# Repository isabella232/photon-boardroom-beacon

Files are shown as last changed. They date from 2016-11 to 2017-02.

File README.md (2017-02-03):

# photon-boardroom-beacon
The boardroom beacon is a physical device mounted to the exterior wall of a boardroom. It has 3 lights indicating meeting room availability in half hour allotments. The first light indicates the boardroom status for the current half hour, the second indicates the next half hour and the third, the half hour after that. So any casual observer can see what the boardroom’s status is, for the next hour and a half. Statuses include “available” (green), “booked” (red) and “illegal” (yellow). An illegal status indicates that a person is in the room but it is not booked. Malfunction will be indicated by all three lights flashing yellow.
##Run
You will need to flash this code to your photon and use the component configurations in the diagram below. When the Photon first plugged in, all the LEDs should blink blue which means it is connected to wifi and waiting for a status message from Mosquitto. Beneath the schematic are instructions on how to send updates to the Photon. The 3D model for the enclosure is also included in this repo as a Sketchup file.
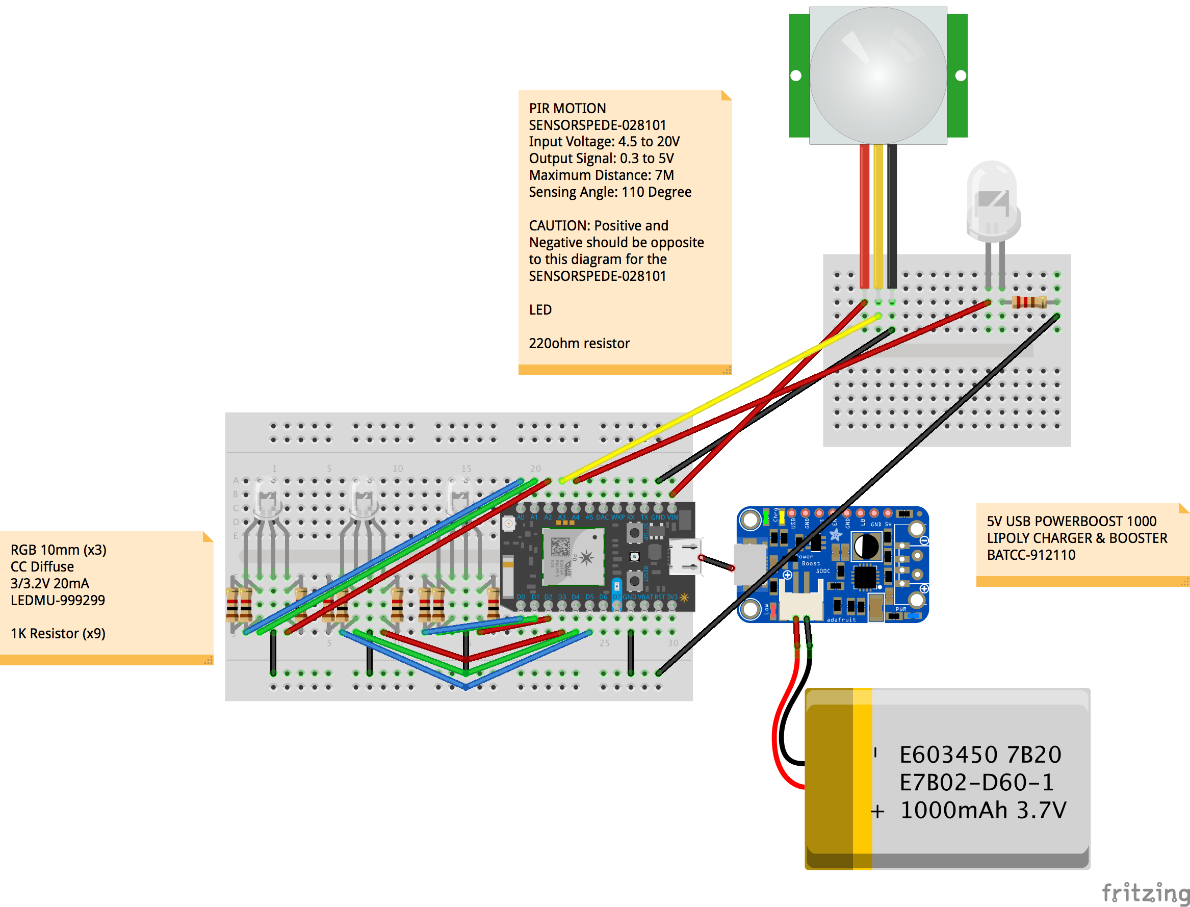
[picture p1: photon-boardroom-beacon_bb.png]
Fritzing

<table>
  <thead>
	<tr>
    <th>Amount</th>
    <th>Part Type</th>
    <th>Properties</th>
    </tr>
  </thead>
  <tbody>
<tr>
    <td>3</td>
    <td>RGB LED (com. cathode, rgb)</td>
    <td class="props">polarity common cathode; pin order rgb; package 5 mm [THT]; rgb RGB; part # LEDMU-999299</td>
</tr><tr>
    <td>1</td>
    <td>LEDs</td>
    <td class="props">variant 10mm; package led10mm</td>
</tr><tr>
    <td>1</td>
    <td>Photon</td>
    <td class="props">pins 24; variant variant 1; name Photon; version 1.0.0; manufacturer Particle</td>
</tr><tr>
    <td>1</td>
    <td>PowerBoost 500 Charger</td>
    <td class="props">variant variant 1; input connector JST; output connector USB</td>
</tr><tr>
    <td>1</td>
    <td>PIR sensor</td>
    <td class="props"></td>
</tr><tr>
    <td>9</td>
    <td>1kΩ Resistor</td>
    <td class="props">resistance 1kΩ; package 2010 [SMD]; tolerance ±5%</td>
</tr><tr>
    <td>1</td>
    <td>220Ω Resistor</td>
    <td class="props">resistance 220Ω; package 1206 [SMD]; tolerance ±5%</td>
</tr><tr>
    <td>1</td>
    <td>LIPO-1000mAh</td>
    <td class="props">variant 1000mAh; package lipo-1000</td>
</tr>
  </tbody>
</table>

##Communicate with the Boardroom-Beacon
This code is meant to work with [Mosquitto MQTT](https://mosquitto.org/) server and [Home Assistant](https://home-assistant.io/). For the photon to get the right calendar data, HASS uses a custom component and configuration [found here](https://github.com/Jam3/.homeassistant). If you don't want to install HASS you can use the Boardroom-Beacon without it by sending messages to Mosquitto through the command line.

###Install Mosquitto
[Download](https://mosquitto.org/download/)
Brew: `brew install mosquitto`

###Update the Mosquitto Configuration File
OSX: `/usr/local/sbin/mosquitto/mosquitto.conf`
Linux: `/etc/mosquitto/mosquitto.conf`

Add the following lines to the very end with your ip & port:
```
# Mosquittoo server IP & port
listener 8883 192.168.2.115
persistence true
persistence_location /var/lib/mosquitto/
persistence_file mosquitto.db
log_dest syslog
log_dest stdout
log_dest topic
log_type error
log_type warning
log_type notice
log_type information
connection_messages true
log_timestamp true
allow_anonymous true
# Add a password https://mosquitto.org/man/mosquitto_passwd-1.html
#password_file /usr/local/etc/mosquitto/pwfile
```
###Run Mosquitto
OSX:
`/usr/local/sbin/mosquitto -c /usr/local/etc/mosquitto/mosquitto.conf`

Brew Background Service(OSX):
`brew services start mosquitto`

Linux:
`sudo mosquitto -v -c /etc/mosquitto/mosquitto.conf`

Background Service (Linux):
`sudo service mosquitto start`

###Publish and Subscribe
You may need to install `mosquitto_sub` & `mosquitto_pub` with Pip3
If you want to verify that Mosquitto is running properly and messages are being sent, you can use `mosquitto_sub`.

`mosquitto_sub -h <your-ip> -p 8883 -v -t 'homeassistant/boardroomBeacon/biggie/slot/0' -u <user> -P <password>`

Omit the user and password if you are not using a `pwfile` file.

Each LED subscribes to its own `slot` topic, `/slot/0`, `/slot/1` or `/slot/2`.
Publish to the status (booked, free, illegal) to the "biggie" boardroom:

`mosquitto_pub -h <your-ip> -p 8883 -t 'homeassistant/boardroomBeacon/biggie/slot/0' -m 'booked'`

The first LED should turn red.

`mosquitto_pub -h <your-ip> -p 8883 -t 'homeassistant/boardroomBeacon/biggie/slot/1' -m 'free'`
The second LED should turn green.

If you move around infront of the motion sensor the first LED should turn yellow.

####Subscribe
`mosquitto_sub -h 192.168.2.115 -p 8883 -v -t 'homeassistant/boardroomBeacon/biggie/slot/0'`
####Publish
`mosquitto_pub -h 192.168.2.115 -p 8883 -t 'homeassistant/boardroomBeacon/biggie/slot/0' -m 'free'`
####Publish wt Credentials
`mosquitto_pub -h 192.168.2.115 -p 8883 -t 'homeassistant/boardroomBeacon/biggie/slot/0' -u "<user>" -P "<password>" -m 'booked'`

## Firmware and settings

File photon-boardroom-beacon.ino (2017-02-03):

#include "SparkJson.h"
#include "MQTT.h"

boolean test = true;
int testLed = D7;
int led1[] = {D0, D1, D2}; //rgb
int led2[] = {D3, D4, D5};
int led3[] = {A0, A1, A2};
// int led3[] = {A2, A1, A0};
String slot1Satus = "";
String slot2Satus = "";
String slot3Satus = "";
boolean slot1HasRecievedMessage = false;
boolean slot2HasRecievedMessage = false;
boolean slot3HasRecievedMessage = false;
boolean isConnected = false;

int pirStatusLed = D7;
int pirInputPin = D6;
int prevPirState = LOW;             // we start, assuming no motion detected
int currentPirState = 0;            // variable for reading the pin status
int calibrateTime = 10000;      // wait for the pir sensor to calibrate

// Generally, you should use "unsigned long" for variables that hold time
// The value will quickly become too large for an int to store
unsigned long previousMillis = 0;        // will store last time LED was updated
unsigned long lastMotionMillis = 0;        // will store last time LED was updated
const long interval = 5000;           // interval at which to blink (milliseconds)

// Log message to cloud, message is a printf-formatted string
void debug(String message, int value) {
    char msg [50];
    sprintf(msg, message.c_str(), value);
    Spark.publish("DEBUG", msg);
    Serial.println(msg);
}

// MQTT
// url structure: /homeassistant/boardroomBeacon/<roomID>/slot/<slotID>/status/<[booked, free, illegal]>
// mosquitto_pub -h 192.168.2.115 -p 8883 -t 'homeassistant/boardroomBeacon/biggie/slot/1' -u pi -P welcome -m 'biggeeeee'
// mosquitto_pub -h 192.168.2.115 -p 8883 -t 'home-assistant/test' -u pi -P welcome -m 'BAm'
void callback(char* topic, byte* payload, unsigned int length);
/*byte server[] = { 10,0,1,39 };*/
byte server[] = { 192,168,2,115 };
int port = 8883;
String usr = "pi";
String pwd = "welcome";
String slot1Topic = "homeassistant/boardroomBeacon/biggie/slot/0";
String slot2Topic = "homeassistant/boardroomBeacon/biggie/slot/1";
String slot3Topic = "homeassistant/boardroomBeacon/biggie/slot/2";
MQTT client(server, port, callback);
// for QoS2 MQTTPUBREL message. this messageid maybe have store list or array structure.
uint16_t qos2messageid = 0;

// recieve message
void callback(char* topic, byte* payload, unsigned int length) {

  // string message, don't parse
  char p[length + 1];
  memcpy(p, payload, length);
  p[length] = NULL;
  String message(p);
  Serial.println("message: "+message);

  String top(topic);
  Serial.println("topic: "+top);
  top.trim();

  if(top.endsWith("0")){
    slot1HasRecievedMessage = true;
    slot1Satus = message;
    if(message == "free" && prevPirState == HIGH){
      Serial.println("illegal!");
      slot1Satus = "illegal";
      setStatus(led1, "illegal");
    } else {
      Serial.println("callback - ok!");
      Serial.println("free");
      setStatus(led1, message);
    }
  } else if (top.endsWith("1")){
    slot2Satus = message;
    slot2HasRecievedMessage = true;
    setStatus(led2, message);
  } else if (top.endsWith("2")){
    slot3Satus = message;
    slot3HasRecievedMessage = true;
    setStatus(led3, message);
  } else {
    Serial.println("No Match!");
  }

  // Parse json payload.
  /*StaticJsonBuffer<200> jsonBuffer;
  JsonObject& command = jsonBuffer.parseObject((char*)payload);
  Serial.println("Command received:");
  command.printTo(Serial);
  Serial.println();*/

}

// QOS ack callback.
// MQTT server sendback message id ack, if use QOS1 or QOS2.
void qoscallback(unsigned int messageid) {
    Serial.print("Ack Message Id:");
    Serial.println(messageid);

    if (messageid == qos2messageid) {
        Serial.println("Release QoS2 Message");
        client.publishRelease(qos2messageid);
    }
}

void setup() {

    Serial.begin(9600);

    /*RGB.control(true);*/
    //pinMode(testLed, OUTPUT);

    // Set up our pins for output
    pinMode( led1[0], OUTPUT);
    pinMode( led1[1], OUTPUT);
    pinMode( led1[2], OUTPUT);

    pinMode( led2[0], OUTPUT);
    pinMode( led2[1], OUTPUT);
    pinMode( led2[2], OUTPUT);

    pinMode( led3[0], OUTPUT);
    pinMode( led3[1], OUTPUT);
    pinMode( led3[2], OUTPUT);

    // initializing/connecting - no previous state cached and not connected to mqtt server yet.
    digitalWrite( led1[0], HIGH);
    digitalWrite( led1[1], LOW);
    digitalWrite( led1[2], HIGH);

    digitalWrite( led2[0], HIGH);
    digitalWrite( led2[1], LOW);
    digitalWrite( led2[2], HIGH);

    digitalWrite( led3[0], HIGH);
    digitalWrite( led3[1], LOW);
    digitalWrite( led3[2], HIGH);

    // add qos callback. If don't add qoscallback, ACK message from MQTT server is ignored.
    client.addQosCallback(qoscallback);

    pinMode( pirStatusLed, OUTPUT );
    pinMode( pirInputPin, INPUT);     // declare sensor as input
    digitalWrite( pirStatusLed, prevPirState );
}

void connect() {
    Serial.print("Connecting to MQTT...");
    while(!client.isConnected()) {
        client.connect("sparkclient", usr, pwd);
        if(client.isConnected()) {
            Serial.println("connected!");
            client.subscribe(slot1Topic);
            client.subscribe(slot2Topic);
            client.subscribe(slot3Topic);
        } else {
            Serial.print(".");
            delay(500);
        }
    }
}

void waiting(int* led){
  digitalWrite( led[0], LOW);
  digitalWrite( led[1], LOW);
  digitalWrite( led[2], HIGH);
  delay(250);
  digitalWrite( led[0], LOW);
  digitalWrite( led[1], LOW);
  digitalWrite( led[2], LOW);
  delay(100);
}

void loop() {

  // if the pir sensor is calibrated
  if ( pirCalibrated() ) {
  // get the data from the sensor
    readTheSensor();
    // report it out, if the state has changed
    reportTheData();
  }

  if (!client.isConnected()) {
    //digitalWrite(testLed, LOW);
    connect();
  } else {
    //digitalWrite(testLed, HIGH);
    if(!slot1HasRecievedMessage){
      waiting(led1);
    }
    if (!slot2HasRecievedMessage){
      waiting(led2);
    }
    if (!slot3HasRecievedMessage){
      waiting(led3);
    }
  }
  // Loop the MQTT client.
  client.loop();

}

// LED Logic
int setStatus(int* led, String status){
  int red = led[0];
  int green = led[1];
  int blue = led[2];
  /*Serial.println(status);*/
  /*debug("status = %d", status);*/
  if(status == "free"){
    Serial.println('free');
    red = LOW;
    green = HIGH;
    blue = LOW;
  } else if (status == "booked") {
    red = HIGH;
    green = LOW;
    blue = LOW;
    Serial.println('booked');
  } else if (status == "illegal") {
    Serial.println("setting to illegal");
    // yellow = Red + green
    red = HIGH;
    green = HIGH;
    blue = LOW;
    Serial.println("illegal");
  } else if (status == "error") {
    red = HIGH;
    green = HIGH;
    blue = HIGH;
  } else if (status == "disconnected") {
    red = HIGH;
    green = HIGH;
    blue = HIGH;
  } else if (status == "waiting") {
    red = LOW;
    green = LOW;
    blue = HIGH;
  } else if (status == "stop") {
    red = LOW;
    green = LOW;
    blue = LOW;
  }
  /*analogWrite( led[0], red);
  analogWrite( led[1], green);
  analogWrite( led[2], blue);*/
  digitalWrite( led[0], red);
  digitalWrite( led[1], green);
  digitalWrite( led[2], blue);
  /*debug("status = %d", status);*/
  return 1;
}

void readTheSensor() {
  currentPirState = digitalRead(pirInputPin);
}

bool pirCalibrated() {
  return millis() - calibrateTime > 0;
}

void reportTheData() {
  //Serial.println(currentPirState);
  // if the sensor reads high
  // or there is now motion
  if (currentPirState == HIGH) {
    Serial.println("hiiiiii");
    lastMotionMillis = millis();
    // the current state is no motion
    // i.e. it's just changed
    // announce this change by publishing an eent
    if (prevPirState == LOW) {
      // we have just turned on
      //Particle.publish("designingiot/s15/motion");
      // Update the current state
      if(slot1Satus == "free"){
        Serial.println("motion - free set to illegal!");
        setStatus(led1, "illegal");
        slot1Satus = "illegal";
      }
      prevPirState = HIGH;
      setLED( prevPirState );
    }
  } else {
    //Serial.println("...");
    if (prevPirState == HIGH) {
      // we have just turned off
      // Update the current state
      if(slot1Satus == "illegal"){
        setStatus(led1, "free");
        slot1Satus = "free";
      }
      prevPirState = LOW;
      setLED( prevPirState );
    }
  }
}

void setLED( int state ) {
  Serial.println("setLed");
  digitalWrite( pirStatusLed, state );
}

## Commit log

2016-11-30 boardroom status mqtt integration
2016-11-30 added fritzing document
    [photon-boardroom-beacon.fzz]
2016-11-30 illegal switch back to legal added
2017-02-03 updated readme and fritzing
    [photon-boardroom-beacon-pcb.fzz, photon-boardroom-beacon.fzz]
